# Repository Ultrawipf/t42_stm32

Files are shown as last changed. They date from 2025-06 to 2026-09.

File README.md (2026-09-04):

## Tennis for two HD

This is a modern reproduction of ["Tennis for two"](https://de.wikipedia.org/wiki/Tennis_for_two) one of the first video games ever made.

The code is structured with a common part in the `Common` folder and chip specific subprojects.

### Variants
#### F303k-NUCLEO 
Designed for the official STM32F303k-Nucleo devboard for use in DIY and Breadboard builds.

Pinouts:
Signal | Pin
---|---
X-Out | A3 (PA4)
Y-Out | A4 (PA5)
Pot left | A0 (PA0)
Pot right | A1 (PA1)
Btn left | A5 (PA6)
Pot left | A6 (PA7)
LED right | D12 (PB4)
LED left | D13 (PB3)

#### F303CB
The latest all in one kit with optional potentiometers and connectors for controllers.

Designed for collections, museums and integrated setups.

The kit is available on [Lectronz](https://lectronz.com/products/LRAzdcngy_EcO1HJ9iuZsVuRM_s1uEzY95U8oW_G/preview).

#### L151
First version shown in the [Project video](https://www.youtube.com/watch?v=GjI3_GtFCSo).

Schematics are available in this repo.

### Links
* [Hackaday.io project blog](https://hackaday.io/project/203185-tennis-for-two-hd)
* [YouTube project video](https://www.youtube.com/watch?v=GjI3_GtFCSo)
* [Buy Tennis for two kits](https://lectronz.com/products/LRAzdcngy_EcO1HJ9iuZsVuRM_s1uEzY95U8oW_G/preview) (Custom builds possible. Contact me for details)

### Pictures
Click to watch YouTube video:

Watch the video (https://www.youtube.com/watch?v=GjI3_GtFCSo)

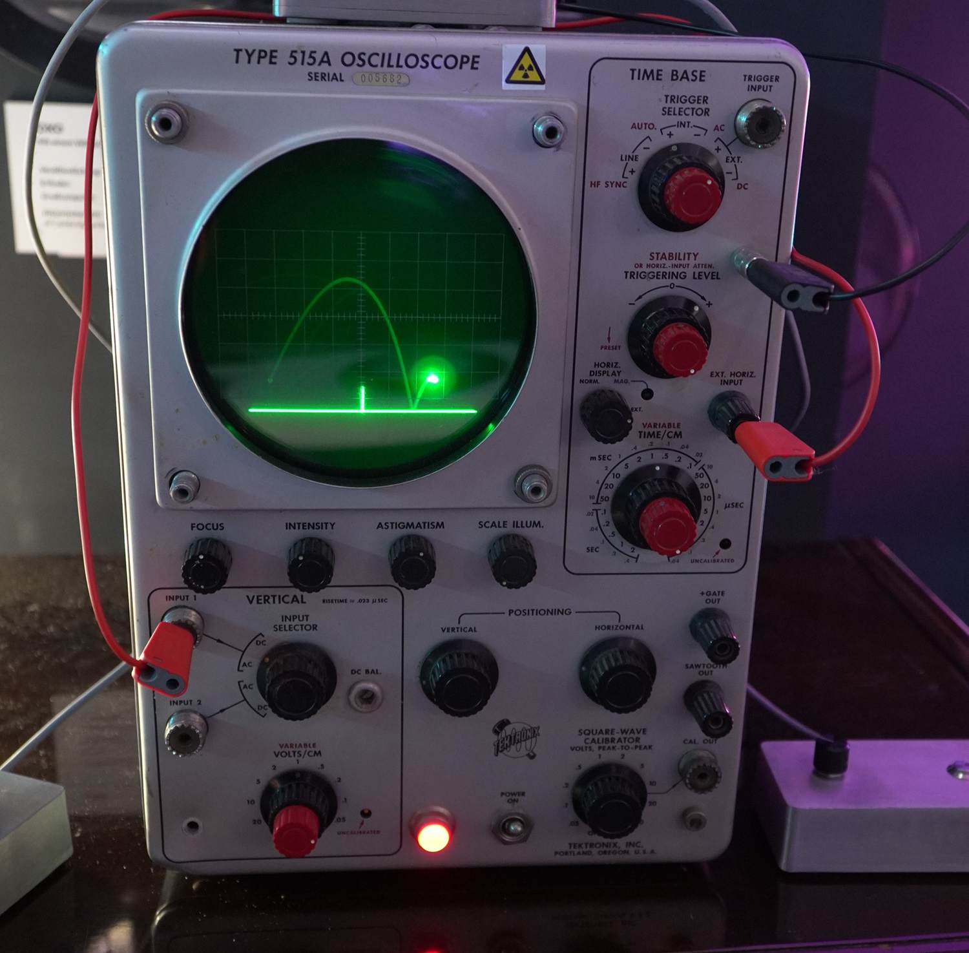
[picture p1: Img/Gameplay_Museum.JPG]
Tek 515A


Hameg scope

Breadboard setup F303k-NUCLEO
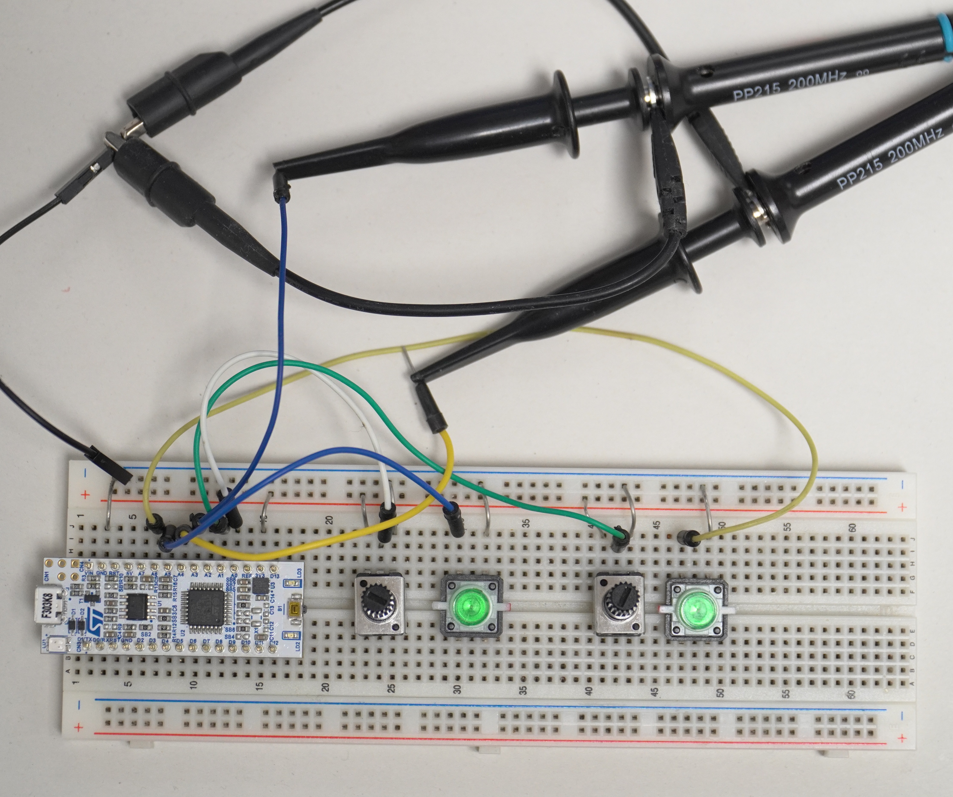
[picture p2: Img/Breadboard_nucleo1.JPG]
Breadboard Nucleo


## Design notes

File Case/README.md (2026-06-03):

# Cases for tennis for two

## Controller
Required parts:
2x 7mm button
2x 7mm potentiometer
8x m3x6 screw
2x 4 wire cable

## Case for Nucleo F303k
Required parts:
4x m3x6 screw
Nucleo F303K

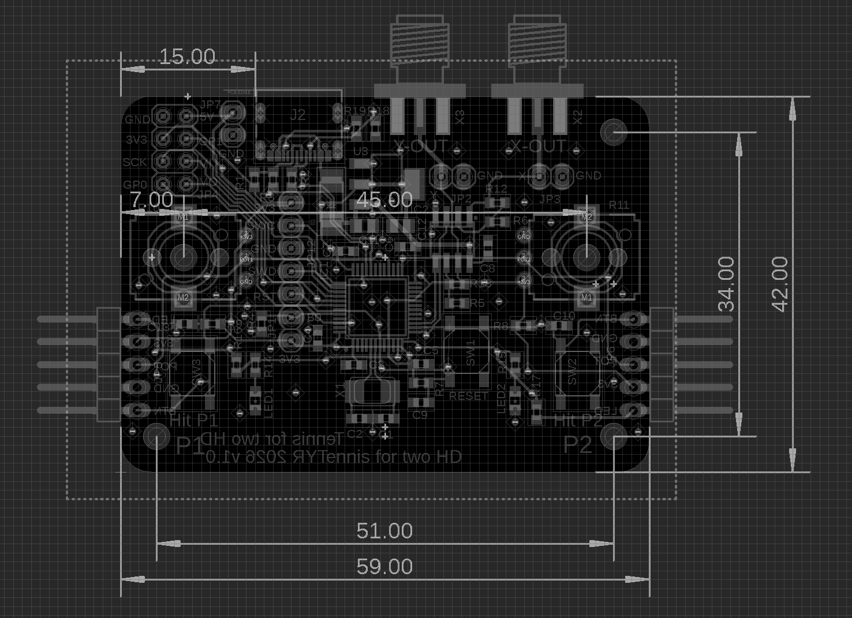
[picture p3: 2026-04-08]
Targets/F303CB/Hardware/dimensions.png

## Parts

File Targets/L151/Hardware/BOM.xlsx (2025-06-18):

Comment | Designator | Footprint | JLCPCB Part #（optional）
 | LED1, LED2 | CHIPLED_0805 | C84256
 | U3 | SOT223 | C6186
1.5k | R1, R4, R5, R6, R14, R15 | R0603 | C22843
100nF | C3, C4, C5, C6, C7, C8, C9, C10, C13 | C0603
10118193-0001LF | J1 | FCI_10118193-0001LF
10k | R7, R8, R9 | R0603 | C25804
15pF | C1, C2 | C0603 | C1644
22 | R2, R3 | R0603 | C23345
3.3k | R12, R13 | R0603 | C22978
4.7uF | C11, C12 | C0805
8MHz | X1 | NX5032 | C115962
LV HC low drop | D1 | SMADIODE | C2480
MCP602SN | IC2 | SO08 | C7377
TS-1187A-B-A-B | SW1, SW2, SW3 | TL3342F160QG/TR | C318884
STM32L151C8T6 | IC1 | QFP50P900X900X160-48N | C9861

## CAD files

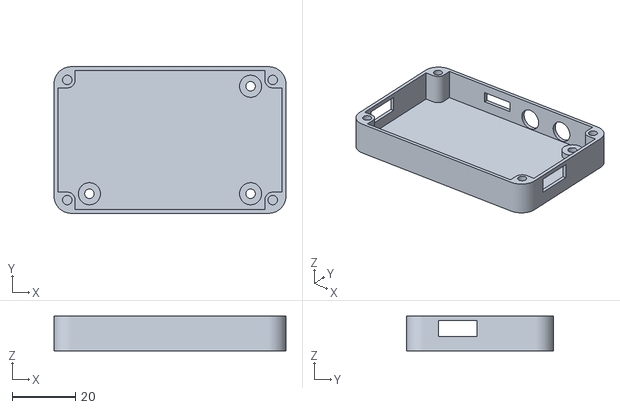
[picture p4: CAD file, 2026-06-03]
Case/Mainbox_compact/Bottom main.stl
73.4 x 46.4 x 11.0

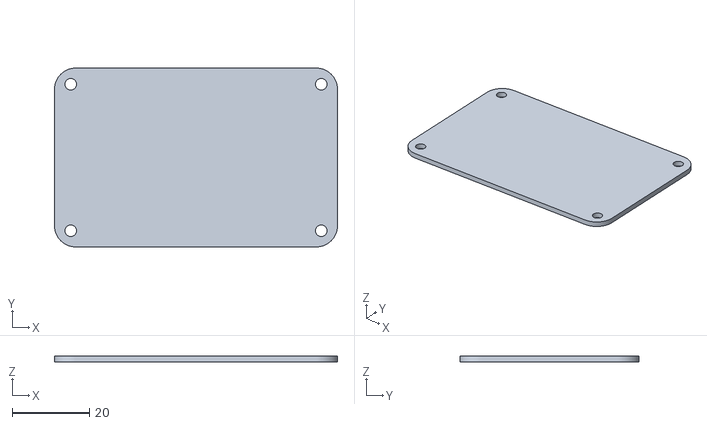
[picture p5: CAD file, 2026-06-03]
Case/Mainbox_compact/Lid main.stl
73.4 x 46.4 x 1.50

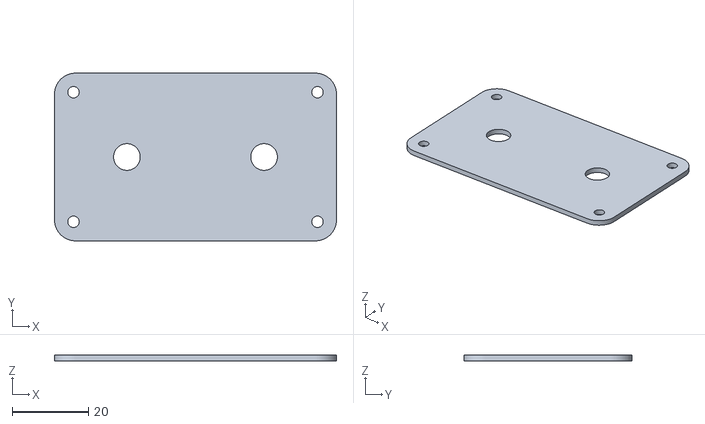
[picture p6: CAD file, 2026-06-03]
Case/Controller/Controller_Top_7mmp.stl
74.0 x 44.0 x 1.50

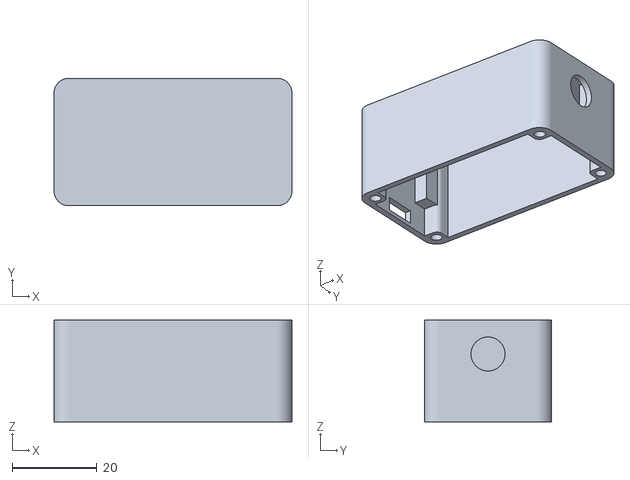
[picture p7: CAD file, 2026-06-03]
Case/Mainbox_nucleo/Nucleo32_base.stl
56.0 x 30.0 x 24.0

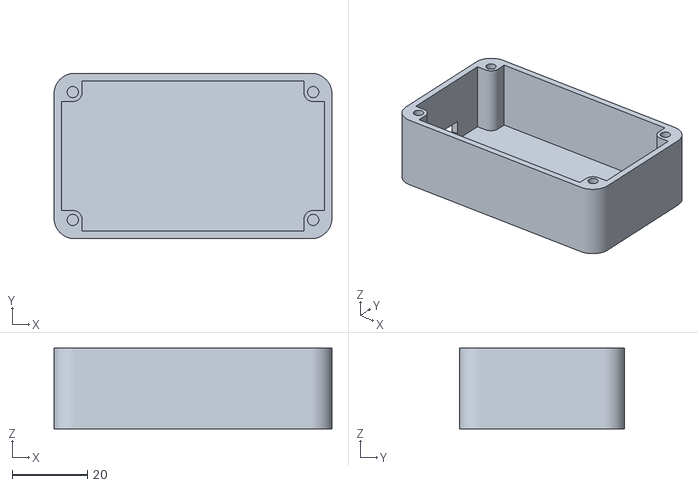
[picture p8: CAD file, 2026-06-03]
Case/Controller/Controller_Bottom_sidecable.stl
74.0 x 44.0 x 21.5

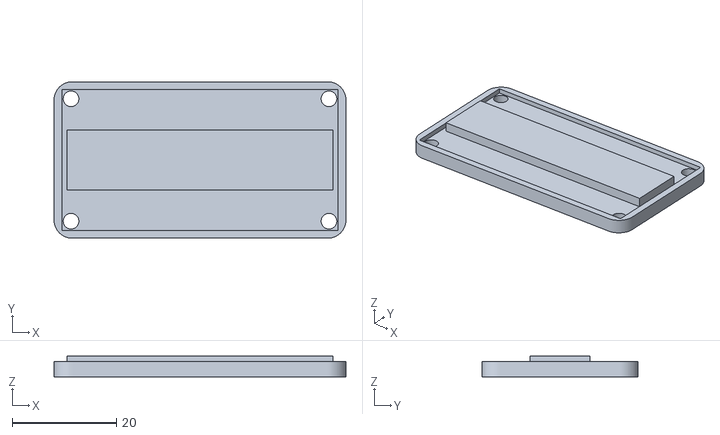
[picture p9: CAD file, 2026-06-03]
Case/Mainbox_nucleo/Nucleo32_lid.stl
56.0 x 30.0 x 4.00

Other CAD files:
Case/Controller/Controller_Bottom_rearcable.stl

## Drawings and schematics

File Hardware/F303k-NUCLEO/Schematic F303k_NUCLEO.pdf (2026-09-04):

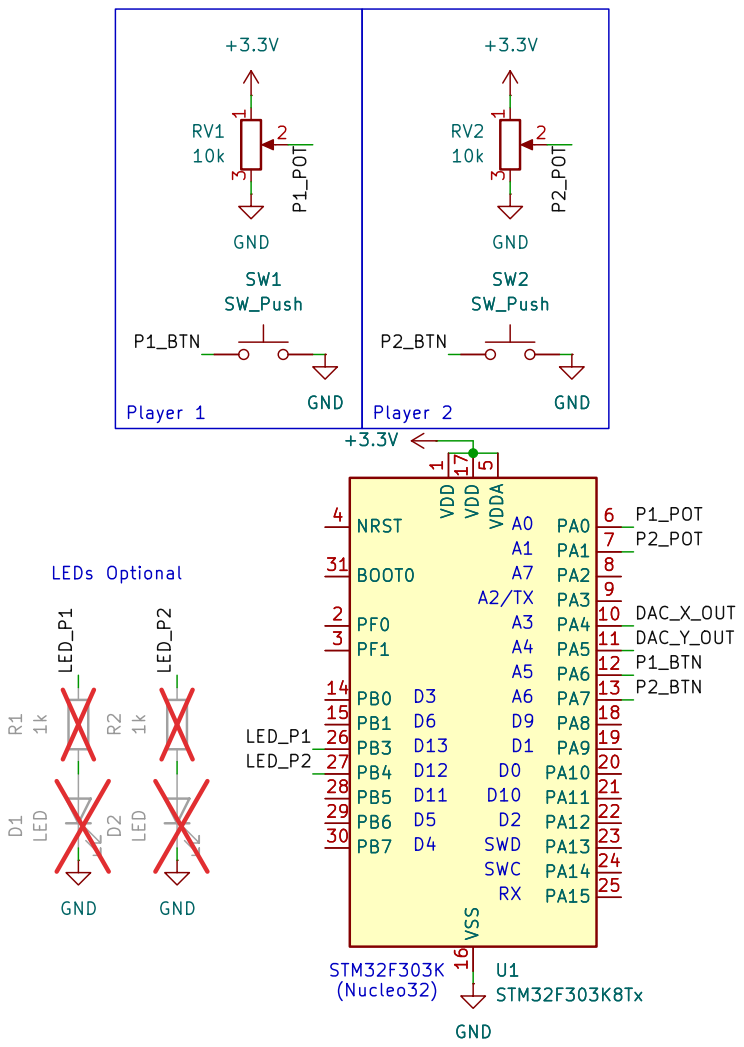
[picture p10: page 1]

1 PF0 2 PF1 3 NRST 4 VDDA 5 PA0 6 PA1 7 PA2 8 PA3 9 PA4 10 PA5 11 PA6 12 PA7 13 PB0 14 PB1 15 VSS 16 VDD 17 PA8 18 PA9 19 PA10 20 PA11 21 PA12 22 PA13 23 PA14 24 PA15 25 PB3 26 PB4 27 PB5 28 PB6 29 PB7 30 BOOT0 31 U1

1 PF0 2 PF1 3 NRST 4 VDDA 5 PA0 6 PA1 7 PA2 8 PA3 9 PA4 10 PA5 11 PA6 12 PA7 13 PB0 14 PB1 15 VSS 16 VDD 17 PA8 18 PA9 19 PA10 20 PA11 21 PA12 22 PA13 23 PA14 24 PA15 25 PB3 26 PB4 27 PB5 28 PB6 29 PB7 30 BOOT0 31 GND

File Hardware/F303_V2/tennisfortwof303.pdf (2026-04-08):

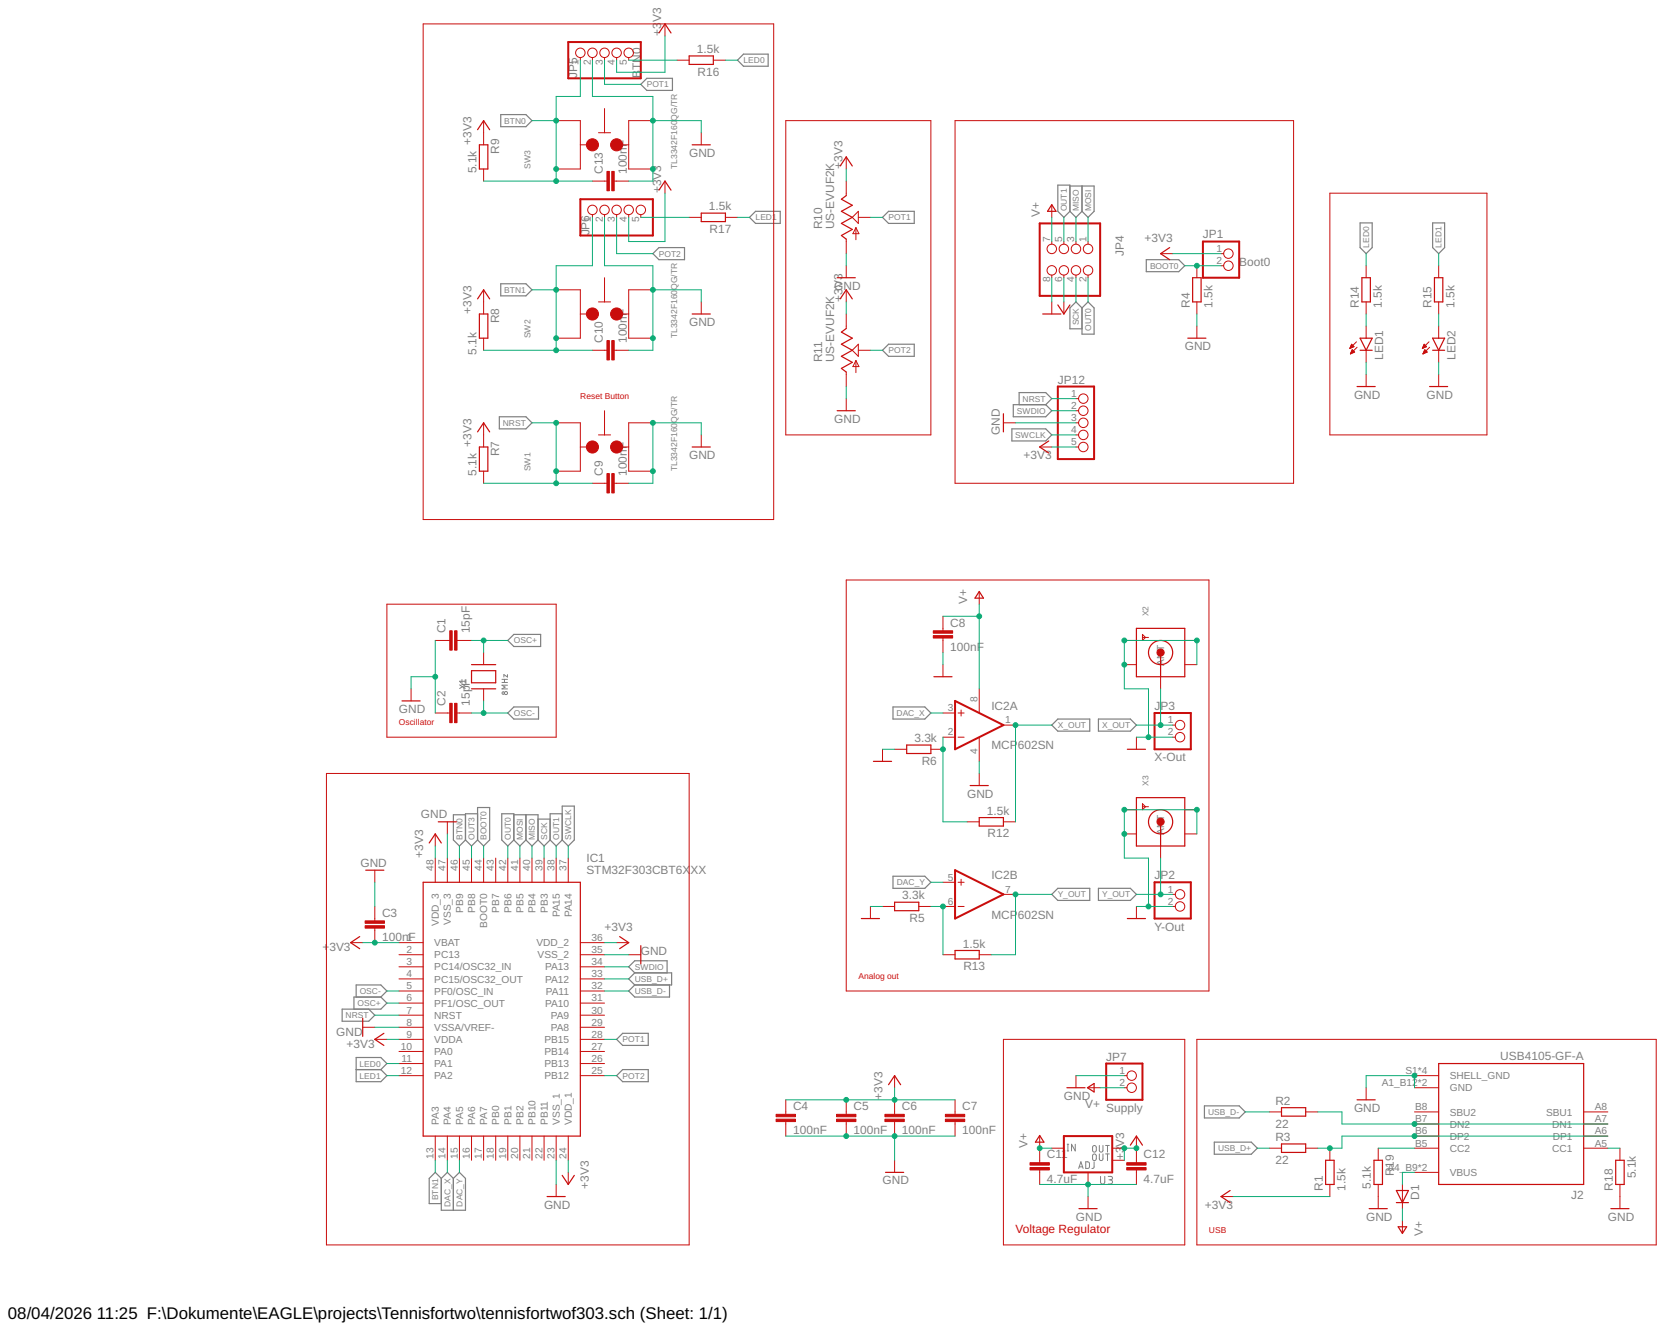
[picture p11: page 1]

08/04/2026 11:25 F:\Dokumente\EAGLE\projects\Tennisfortwo\tennisfortwof303.sch (Sheet: 1/1)

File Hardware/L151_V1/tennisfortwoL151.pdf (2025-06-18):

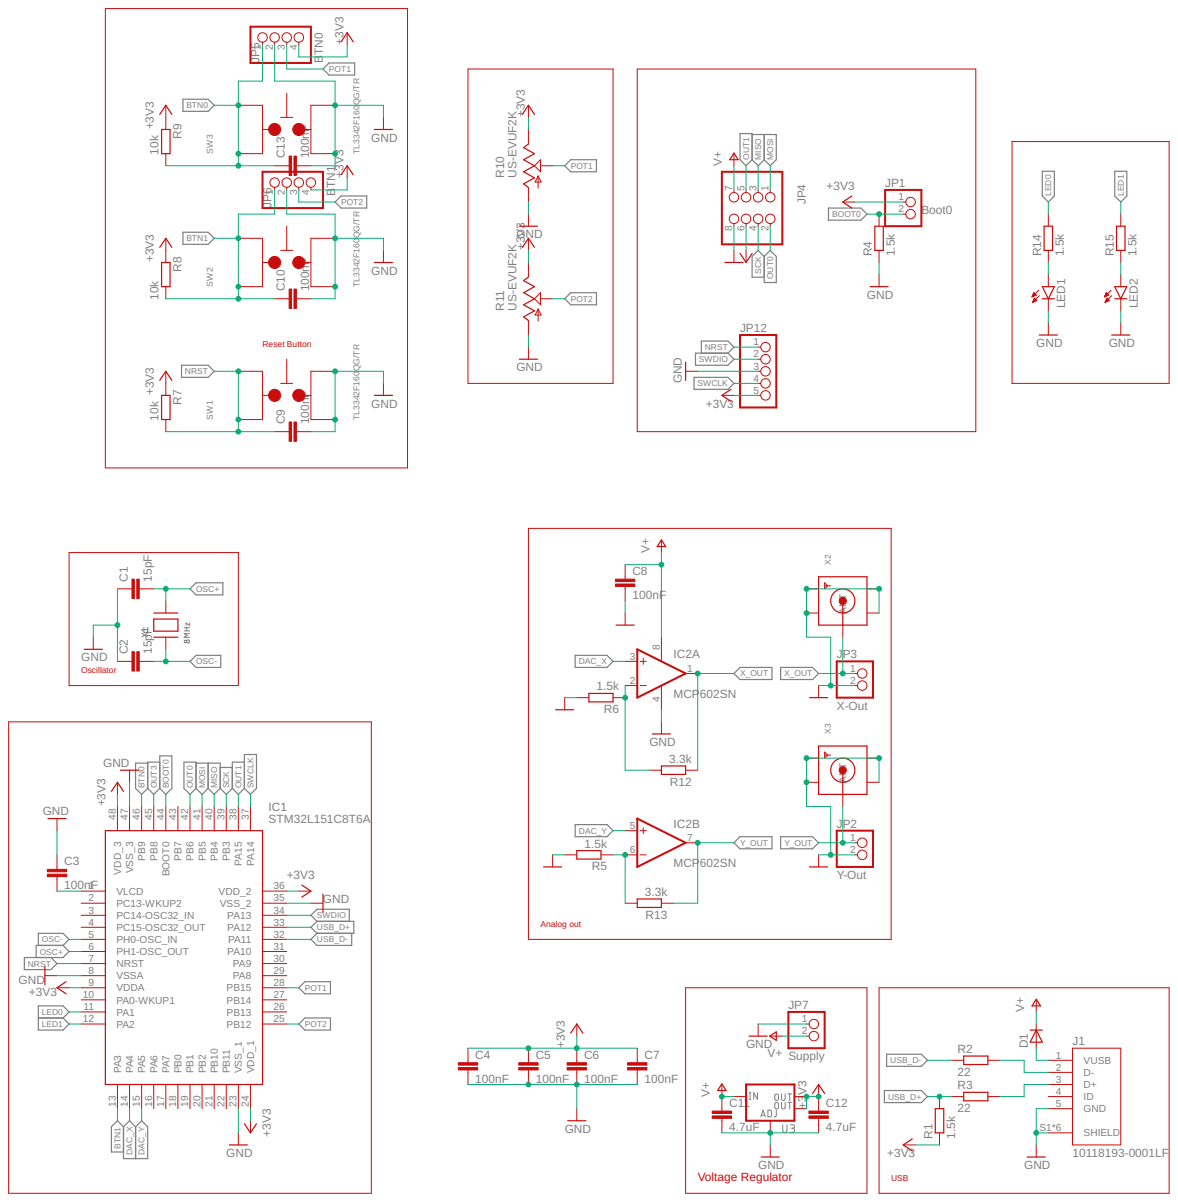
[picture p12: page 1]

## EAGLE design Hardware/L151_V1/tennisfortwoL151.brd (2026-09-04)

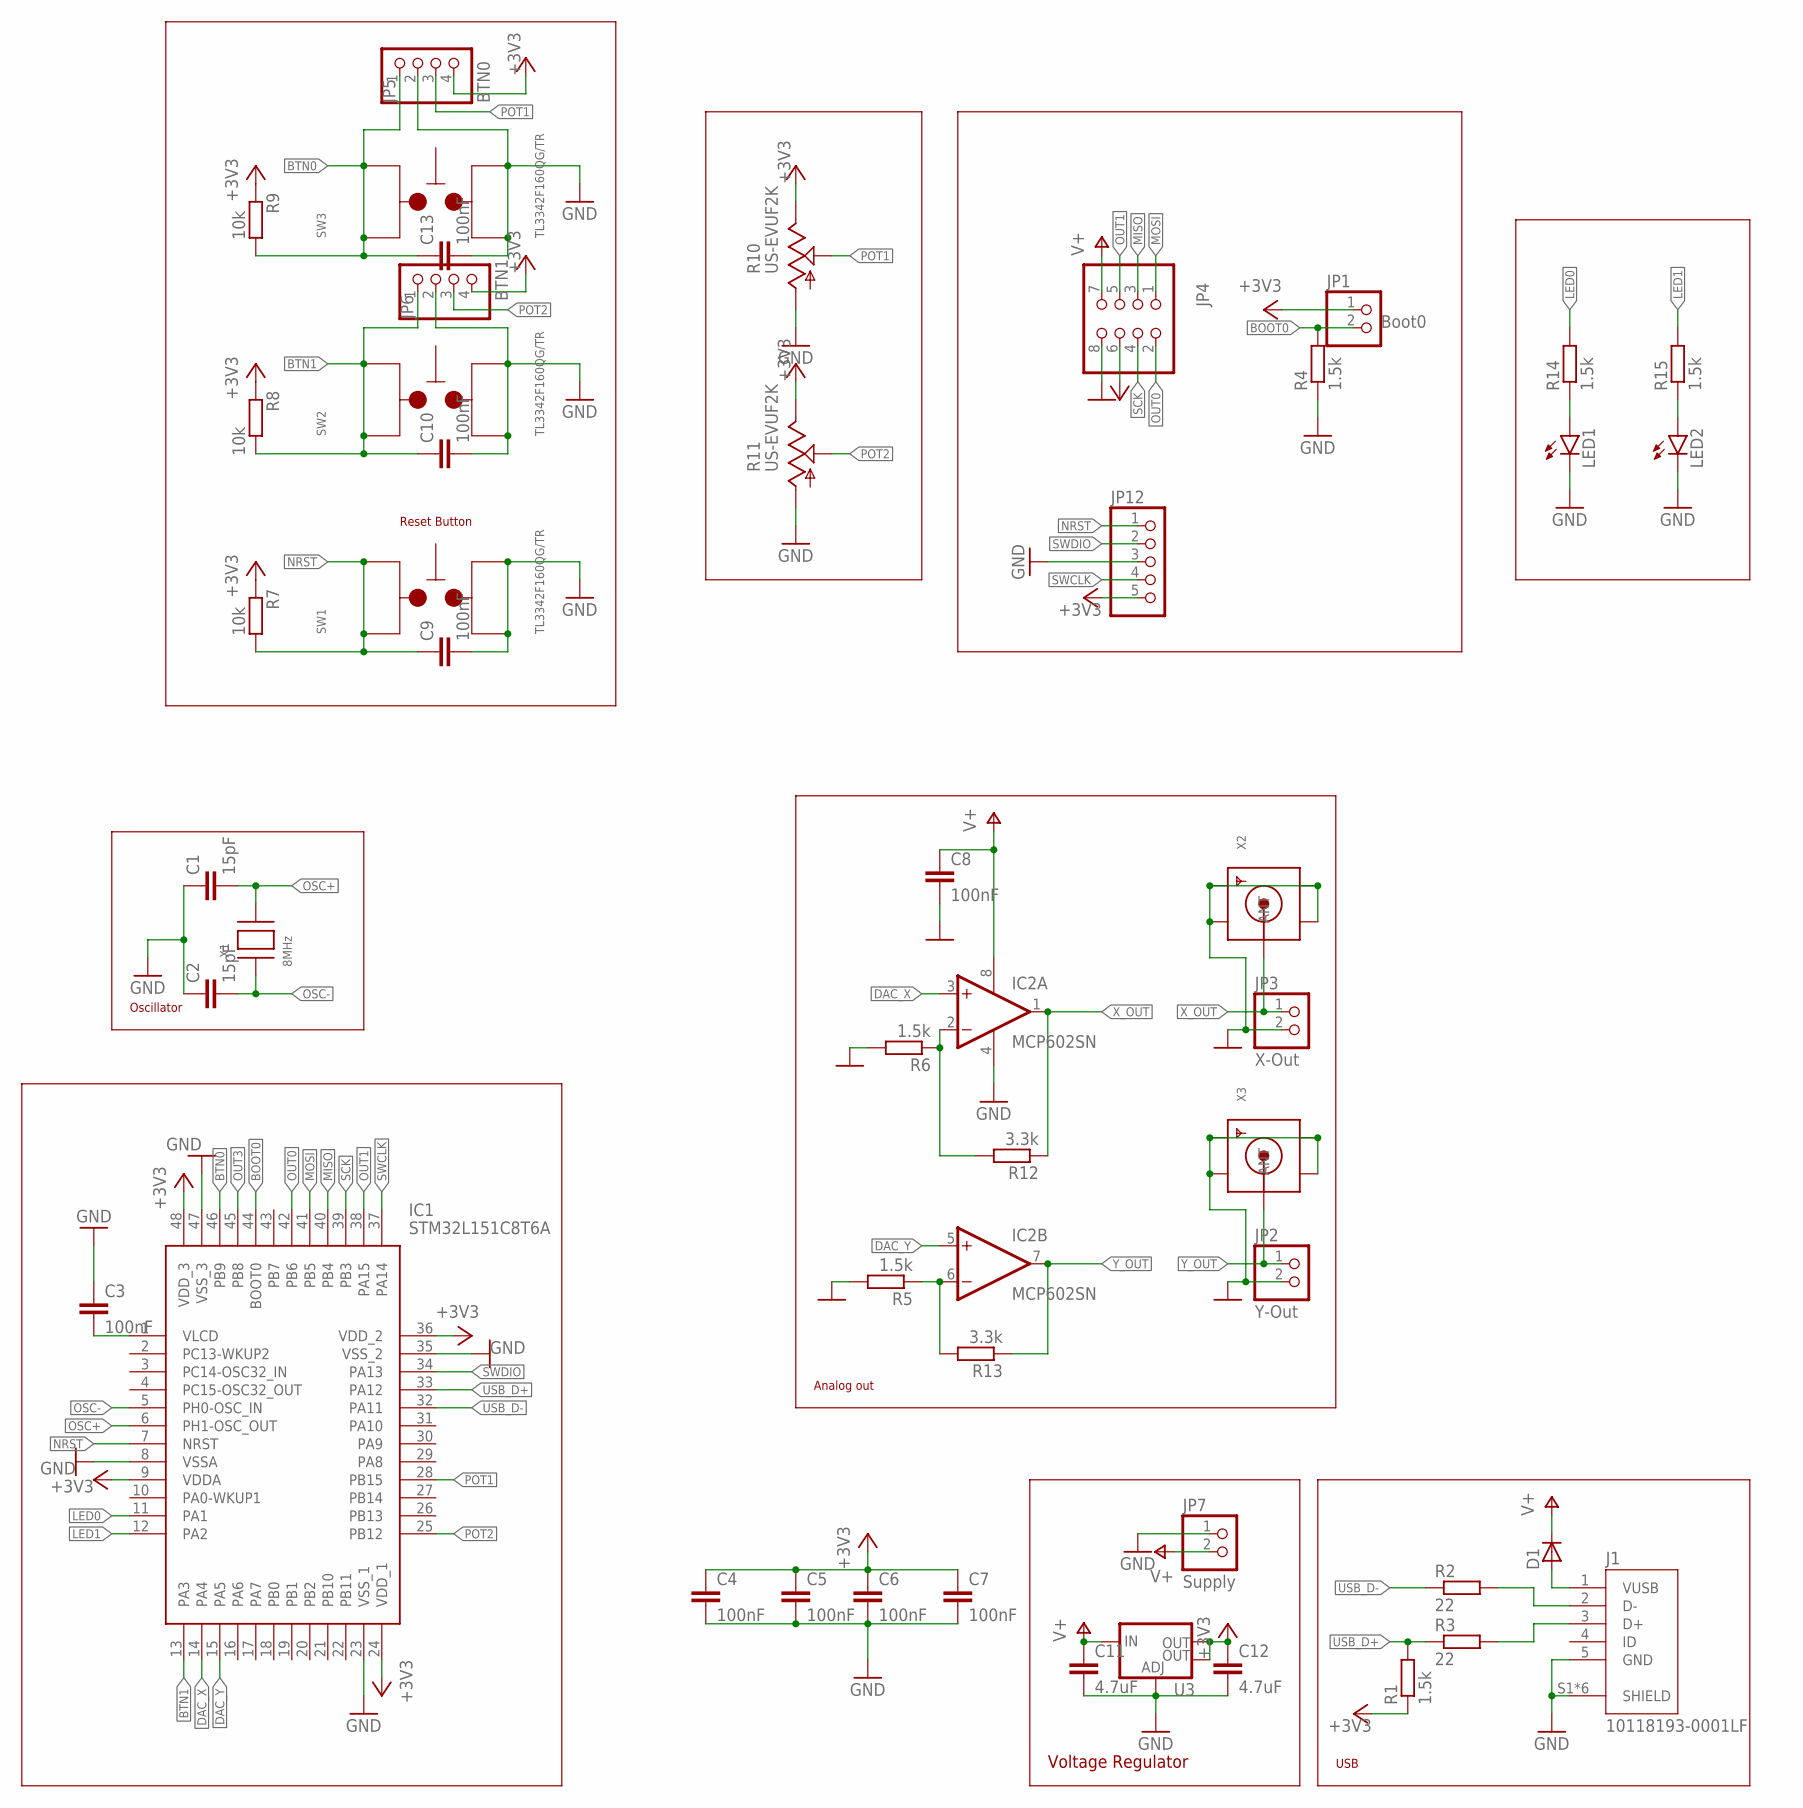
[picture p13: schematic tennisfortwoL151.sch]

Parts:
C1, C2: 15pF; C0603
C3, C4, C5, C6, C7, C8, C9, C10, C13: 100nF; C0603
C11, C12: 4.7uF; C0805
D1: DIODESMA; SMADIODE
IC1: STM32L151C8T6A; QFP50P900X900X160-48N
IC2: MCP602SN; SO08
J1: 10118193-0001LF; FCI_10118193-0001LF
JP1: Boot0; 1X02
JP2: Y-Out; 1X02
JP3: X-Out; 1X02
JP4: PINHD-2X4; 2X04
JP5: BTN0; 1X04/90
JP6: BTN1; 1X04/90
JP7: Supply; 1X02
JP12: PINHD-1X5; 1X05
LED1, LED2: LEDCHIPLED_0805; CHIPLED_0805
R1, R4, R5, R6, R14, R15: 1.5k; R0603
R2, R3: 22; R0603
R7, R8, R9: 10k; R0603
R10, R11: US-EVUF2K; EVUFXK
R12, R13: 3.3k; R0603
SW1, SW2, SW3: TL3342F160QG/TR
U3: V_REG_LM1117SOT223; SOT223
X1: 8MHz; NX5032
X2, X3: SMACONNECTOR_EDGE; SMA_EDGELAUNCH

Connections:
+3V3: C4.1, C5.1, C6.1, C7.1, C12.1, IC1.9 (VDDA), IC1.24 (VDD_1), IC1.36 (VDD_2), IC1.48 (VDD_3), JP1.1, JP4.6, JP5.4, JP6.4, JP12.5, R1.1, R7.1, R8.1, R9.1, R10.3 (E), R11.3 (E), U3.2 (OUT), U3.4 (OUT)
BOOT0: IC1.44 (BOOT0), JP1.2, R4.2
BTN0: C13.1, IC1.46 (PB9), JP5.1, R9.2, SW3.3, SW3.4
BTN1: C10.1, IC1.13 (PA3), JP6.1, R8.2, SW2.3, SW2.4
DAC_X: IC1.14 (PA4), IC2.3 (+IN)
DAC_Y: IC1.15 (PA5), IC2.5 (+IN)
GND: C1.1, C2.1, C3.1, C4.2, C5.2, C6.2, C7.2, C8.2, C9.2, C10.2, C11.2, C12.2, C13.2, IC1.8 (VSSA), IC1.23 (VSS_1), IC1.35 (VSS_2), IC1.47 (VSS_3), IC2.4 (V-), J1.5 (GND), J1.S1 (SHIELD), J1.S2 (SHIELD), J1.S3 (SHIELD), J1.S4 (SHIELD), J1.S5 (SHIELD), J1.S6 (SHIELD), JP2.2, JP3.2, JP4.8, JP5.2, JP6.2, JP7.1, JP12.3, LED1.C, LED2.C, R4.1, R5.2, R6.2, R10.1 (A), R11.1 (A), SW1.1, SW1.2, SW2.1, SW2.2, SW3.1, SW3.2, U3.1 (ADJ), X2.GND@1 (GND4), X2.GND@2 (GND3), X2.GND@3 (GND2), X2.GND@4 (GND1), X3.GND@1 (GND4), X3.GND@2 (GND3), X3.GND@3 (GND2), X3.GND@4 (GND1)
LED0: IC1.11 (PA1), R14.2
LED1: IC1.12 (PA2), R15.2
MISO: IC1.40 (PB4), JP4.3
MOSI: IC1.41 (PB5), JP4.1
unnamed: C3.2, IC1.1 (VLCD)
unnamed: D1.A, J1.1 (VUSB)
unnamed: LED1.A, R14.1
unnamed: LED2.A, R15.1
unnamed: J1.2 (D-), R2.2
unnamed: J1.3 (D+), R3.2
unnamed: IC2.2 (-IN), R6.1, R12.2
unnamed: IC2.6 (-IN), R5.1, R13.2
NRST: C9.1, IC1.7 (NRST), JP12.1, R7.2, SW1.3, SW1.4
OSC+: C1.2, IC1.6 (PH1-OSC_OUT), X1.P$2
OSC-: C2.2, IC1.5 (PH0-OSC_IN), X1.P$1
OUT0: IC1.42 (PB6), JP4.2
OUT1: IC1.38 (PA15), JP4.5
OUT3: IC1.45 (PB8)
POT1: IC1.28 (PB15), JP5.3, R10.2 (S)
POT2: IC1.25 (PB12), JP6.3, R11.2 (S)
SCK: IC1.39 (PB3), JP4.4
SWCLK: IC1.37 (PA14), JP12.4
SWDIO: IC1.34 (PA13), JP12.2
USB_D+: IC1.33 (PA12), R1.2, R3.1
USB_D-: IC1.32 (PA11), R2.1
V+: C8.1, C11.1, D1.C, IC2.8 (V+), JP4.7, JP7.2, U3.3 (IN)
X_OUT: IC2.1 (OUT), JP3.1, R12.1, X2.P (ANT)
Y_OUT: IC2.7 (OUT), JP2.1, R13.1, X3.P (ANT)

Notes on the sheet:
Oscillator
USB
Voltage Regulator
Reset Button
Analog out

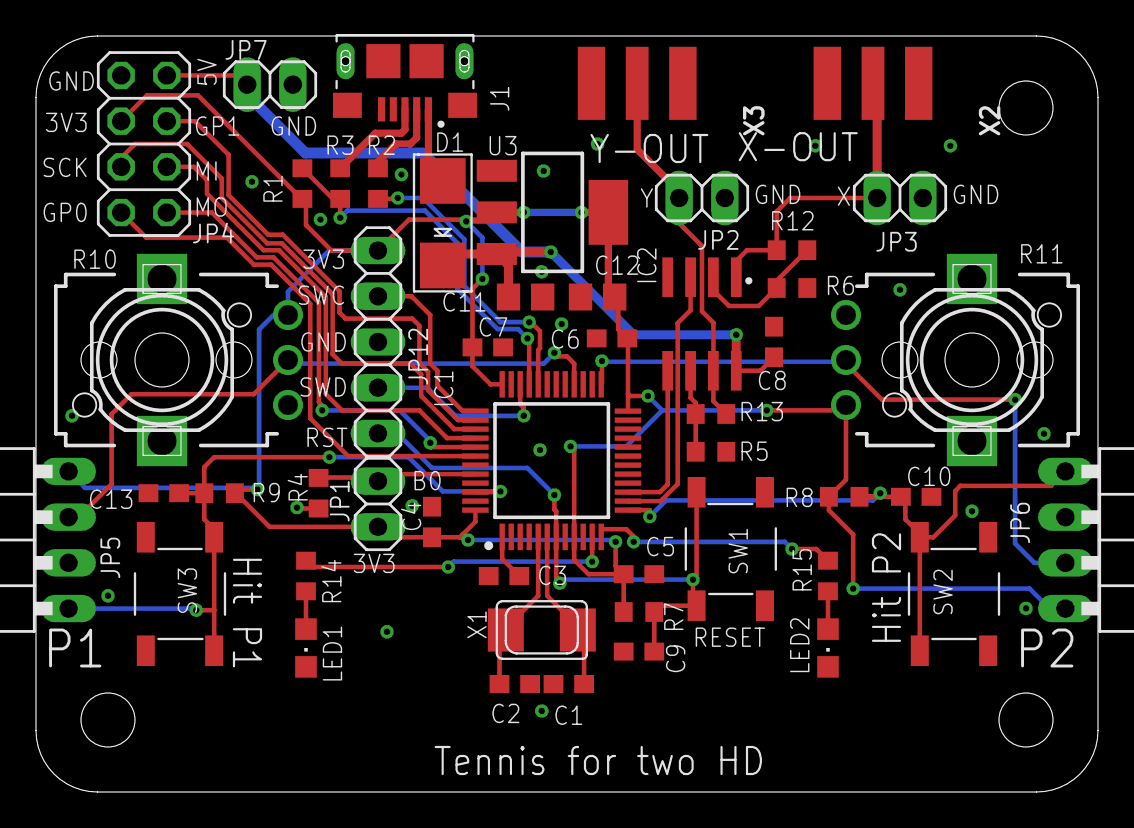
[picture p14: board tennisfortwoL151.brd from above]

Board: 2 copper layers, 59.0 x 42.0 mm, 49 parts (0 on the bottom side), 34 nets.

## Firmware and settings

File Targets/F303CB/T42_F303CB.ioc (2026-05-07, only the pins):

Mcu.UserName=STM32F303CBTx
PA1.GPIO_Label=LED0
PA1.Signal=GPIO_Output
PA11.Signal=USB_DM
PA12.Signal=USB_DP
PA13.Signal=SYS_JTMS-SWDIO
PA14.Signal=SYS_JTCK-SWCLK
PA2.GPIO_Label=LED1
PA2.Signal=GPIO_Output
PA3.GPIO_Label=BTN2
PA3.Signal=GPIO_Input
PA4.Signal=COMP_DAC1_group
PA5.Signal=COMP_DAC2_group
PB12.Signal=ADC4_IN3
PB15.Signal=ADC4_IN5
PB9.GPIO_Label=BTN1
PB9.Signal=GPIO_Input
PF0-OSC_IN.Signal=RCC_OSC_IN
PF1-OSC_OUT.Signal=RCC_OSC_OUT

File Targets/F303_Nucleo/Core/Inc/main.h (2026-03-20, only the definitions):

#define TIM_DAC htim2
#define TIM_FRAME htim6
#define TIM_GAME htim7
#define DAC_OUT hdac1
#define ADC_POTS hadc1
#define MCO_Pin GPIO_PIN_0
#define MCO_GPIO_Port GPIOF
#define VCP_TX_Pin GPIO_PIN_2
#define VCP_TX_GPIO_Port GPIOA
#define BTN1_Pin GPIO_PIN_6
#define BTN1_GPIO_Port GPIOA
#define BTN2_Pin GPIO_PIN_7
#define BTN2_GPIO_Port GPIOA
#define SWDIO_Pin GPIO_PIN_13
#define SWDIO_GPIO_Port GPIOA
#define SWCLK_Pin GPIO_PIN_14
#define SWCLK_GPIO_Port GPIOA
#define VCP_RX_Pin GPIO_PIN_15
#define VCP_RX_GPIO_Port GPIOA
#define LED0_Pin GPIO_PIN_3
#define LED0_GPIO_Port GPIOB
#define LED1_Pin GPIO_PIN_4
#define LED1_GPIO_Port GPIOB

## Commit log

2025-06-18 Added hardware folder
    [BOM.xlsx, tennisfortwoL151.brd, tennisfortwoL151.sch]
2025-06-20 Update timers for better stability
    [main.h, t42.c]
2026-01-18 Restructured project
    [BOM.xlsx, tennisfortwo (1).cfg, tennisfortwo.cfg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]
2026-01-18 L151 using tim6 for adc trigger
2026-01-18 More accurate air resistance
2026-05-01 Fix adc cal for L1
    [t42.c]
2026-06-03 Added printable case components
    [Bottom main.stl, Controller_Bottom_rearcable.stl, Controller_Bottom_sidecable.stl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]
2026-09-04 Added schematics
    [tennisfortwoL151.brd, tennisfortwoL151.sch, tennisfortwof303.sch]

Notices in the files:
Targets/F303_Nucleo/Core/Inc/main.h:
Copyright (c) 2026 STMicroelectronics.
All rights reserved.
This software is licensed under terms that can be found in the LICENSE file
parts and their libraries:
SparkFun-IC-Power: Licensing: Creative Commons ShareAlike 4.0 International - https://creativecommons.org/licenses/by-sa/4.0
